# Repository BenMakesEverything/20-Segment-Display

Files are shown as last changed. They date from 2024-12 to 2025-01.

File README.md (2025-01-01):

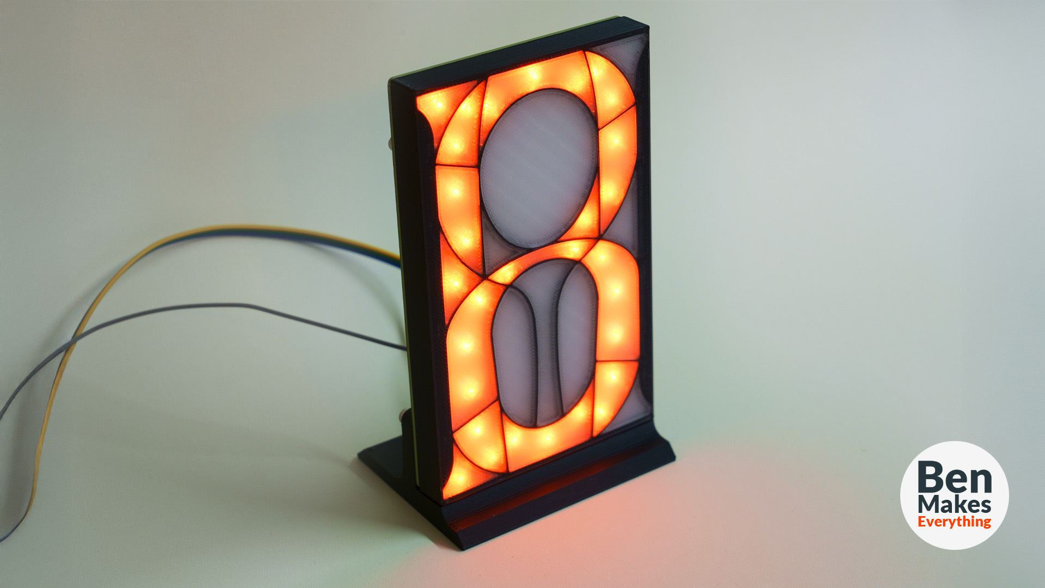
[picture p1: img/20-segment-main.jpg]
20 Segemnt 3D printed display


# 3D Printable 20 Segment Display
### This is a fully 3D printed segmented display designed for use with 5mm LEDs
You can use any type, but it was designed to be used in conjunction with the WS2812 through-hole type, soldered to a custom PCB.

# Parts list - for 1 display
* (38) WS2812 5mm LED: https://www.aliexpress.us/item/3256803179127817.html
* (1) 10uF capacitor
* (2) 1x3 male pin headers
* (1) PCB
* (4) M3 heat-set threaded inserts

All of the 3D files are available in .stl and .step format in the "Objects" folder.

The Arduino code for this version is available in the "Code" folder. It requires that you install the Adafruit neopixel libary within the Arduino IDE. There are now 2 versions: the standard one as seen in the video, and a scrolling version that lets you display longer messages.

In the "PCBs" folder you will find 2 zip files. 20-Segment-THT-KiCad.zip is a zipped folder of everything you need to open this in KiCad version 8+. 20-Segment-THT.kicad_pcb.zip contains gerber/drill files. Please note, the BOM file was auto generated, but I did not use it in getting these manufactured and can't confirm that the info is correct. I manually soldered the parts myself so if you want to get these manufactured in complete form, you'll likely need to specify the part numbers yourself.

The KiCad symbols and footprints for the WS2812 were based on these, created by bitluni: (https://github.com/bitluni/magnetMatrix6x6).

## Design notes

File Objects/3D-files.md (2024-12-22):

20-segment-body: the main display panel, for use with 5mm LEDs. Print with black and clear PETG.
20-segment-stand-left-end: use this for the left-most panel's stand
20-segment-stand-middle: use this for the middle panels' stands
20-segment-stand-right-end: use this for the right-most panel's stand

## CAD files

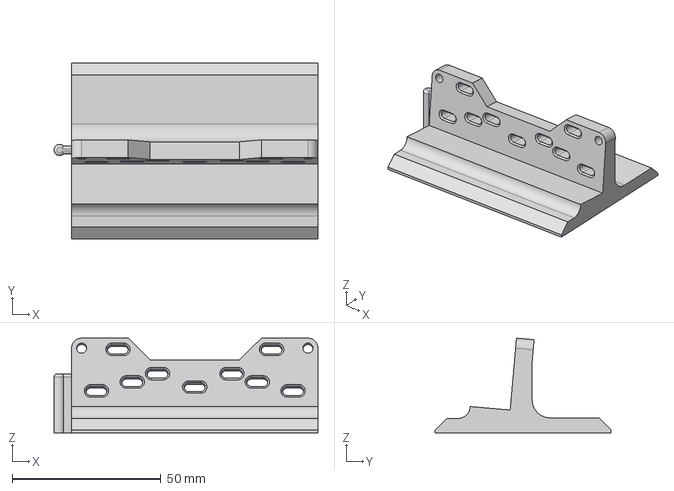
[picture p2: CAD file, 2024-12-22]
Objects/20-segment-stand-right-end.step
88.7 x 58.9 x 31.8 mm

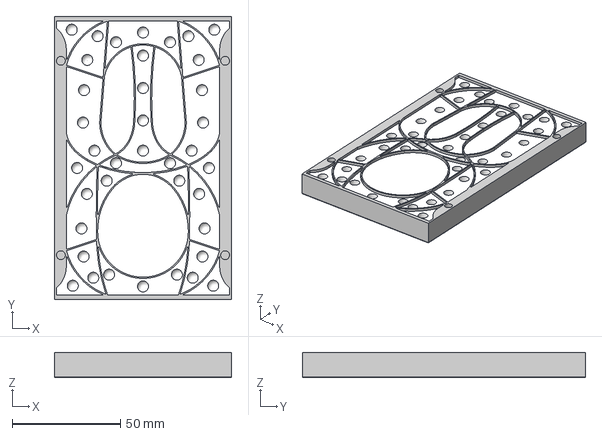
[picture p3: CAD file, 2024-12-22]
Objects/20-segment-body.step
82.0 x 131.0 x 11.6 mm

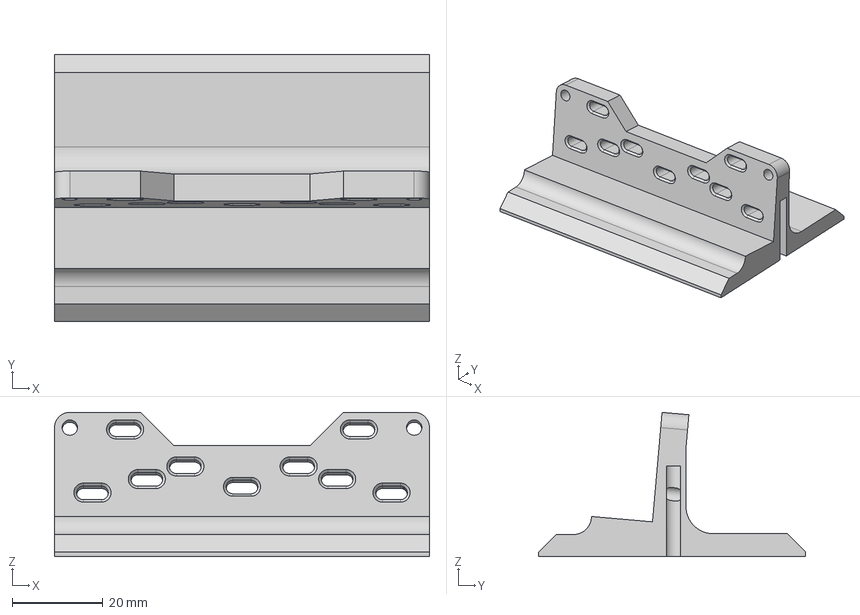
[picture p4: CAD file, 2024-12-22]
Objects/20-segment-stand-left-end.step
82.7 x 58.9 x 31.8 mm

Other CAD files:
Objects/20-segment-stand-middle.step
Objects/20-segment-body.stl
Objects/20-segment-stand-left-end.stl
Objects/20-segment-stand-middle.stl
Objects/20-segment-stand-right-end.stl

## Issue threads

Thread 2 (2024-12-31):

I think that a middle I and T actually look pretty OK

traverseda, 2024-12-31:
Can't include image links in youtube, so I'll post it here.

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

BenMakesEverything, 2025-01-02:
Those are certainly an option - I mainly didn't like the center bar sticking out like that. For now, I've just changed the t to a lower case version, at the suggestion of a couple people in the comments.
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

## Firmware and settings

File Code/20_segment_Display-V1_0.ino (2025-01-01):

/*Created by: Ben Makes Everything - youtube.com/@benmakeseverything*/
#include <Adafruit_NeoPixel.h>

#define dataPin 3      //Neopixel control dataPin
#define NUM_PANELS 10  //Number of display panels chained together

int numPixels = NUM_PANELS * 38;  // Total number of NeoPixels - 38 per display

Adafruit_NeoPixel pixels = Adafruit_NeoPixel(numPixels, dataPin, NEO_RGB + NEO_KHZ800);

const byte numChars = 11;  //MAX ammount of chars that can be input = #displays + 1
char myData[numChars];     // an array to store the received data
boolean newData = false;   // for checking serial

int digit = 0;

//Byte data array for all characters, follows pixel order from PCB
const uint8_t digitSegments[][5] = {
  { 0b00000000, 0b00000000, 0b00000000, 0b00000000, 0b00000000 }, /*SPACE*/
  { 0b00000011, 0b11101111, 0b10111101, 0b11101111, 0b10111000 }, /*0*/
  { 0b00000011, 0b11110000, 0b00000000, 0b00000001, 0b11111000 }, /*1*/
  { 0b00001100, 0b01111111, 0b10111000, 0b01101111, 0b10110100 }, /*2*/
  { 0b00001111, 0b11101111, 0b10000000, 0b01101111, 0b10110100 }, /*3*/
  { 0b00001111, 0b11110000, 0b00000011, 0b11110001, 0b11111000 }, /*4*/
  { 0b00001111, 0b11101111, 0b10000011, 0b11111111, 0b11000000 }, /*5*/
  { 0b00001111, 0b11101111, 0b10111101, 0b11101111, 0b10000000 }, /*6*/
  { 0b00001100, 0b00000001, 0b11111000, 0b01111111, 0b11110100 }, /*7*/
  { 0b00001111, 0b11101111, 0b10111011, 0b11101111, 0b10110100 }, /*8*/
  { 0b00001111, 0b11101111, 0b10000011, 0b11101111, 0b10111100 }, /*9*/
  { 0b00001111, 0b11110001, 0b11111101, 0b11101111, 0b10111000 }, /*A*/
  { 0b00001111, 0b11101111, 0b11111101, 0b11111111, 0b10110100 }, /*B*/
  { 0b00000000, 0b01101111, 0b10111101, 0b11101111, 0b10000000 }, /*C*/
  { 0b00000011, 0b11101111, 0b11111101, 0b11111111, 0b10111000 }, /*D*/
  { 0b00001100, 0b01111111, 0b11111101, 0b11111111, 0b11000000 }, /*E*/
  { 0b00001100, 0b00000001, 0b11111101, 0b11111111, 0b11000000 }, /*F*/
  { 0b00000011, 0b11111111, 0b10111101, 0b11101111, 0b10000000 }, /*G*/
  { 0b00001111, 0b11110001, 0b11111101, 0b11110001, 0b11111000 }, /*H*/
  { 0b00000011, 0b11110000, 0b00000000, 0b00000001, 0b11111000 }, /*I*/
  { 0b00000011, 0b11101111, 0b10000000, 0b00000001, 0b11111000 }, /*J*/
  { 0b00001111, 0b11110001, 0b11111101, 0b11110000, 0b00110100 }, /*K*/
  { 0b00000000, 0b01111111, 0b11111101, 0b11110000, 0b00000000 }, /*L*/
  { 0b11111111, 0b11110001, 0b11111111, 0b11110001, 0b11111100 }, /*M*/
  { 0b00000011, 0b11110001, 0b11111101, 0b11111111, 0b10111000 }, /*N*/
  { 0b00000011, 0b11101111, 0b10111101, 0b11101111, 0b10111000 }, /*O*/
  { 0b00001100, 0b00000001, 0b11111101, 0b11111111, 0b10110100 }, /*P*/
  { 0b00000011, 0b11111111, 0b10111101, 0b11101111, 0b10111000 }, /*Q*/
  { 0b00001111, 0b11110001, 0b11111101, 0b11111111, 0b10110100 }, /*R*/
  { 0b00001111, 0b11101111, 0b10000011, 0b11101111, 0b10000000 }, /*S*/
  //{ 0b00000011, 0b11110000, 0b00000000, 0b01111111, 0b11111000 }, /*T (uppercase)*/
  { 0b00001100, 0b01101111, 0b10111101, 0b11110000, 0b00000000 }, /*t (lowercase)*/
  { 0b00000011, 0b11111111, 0b11111101, 0b11110001, 0b11111000 }, /*U*/
  { 0b00000011, 0b11101111, 0b10111101, 0b11110001, 0b11111000 }, /*V*/
  { 0b11110011, 0b11111111, 0b11111101, 0b11110001, 0b11111000 }, /*W*/
  { 0b00001111, 0b11110001, 0b11111011, 0b11110001, 0b11110100 }, /*X*/
  { 0b00001111, 0b11101111, 0b10000011, 0b11110001, 0b11111100 }, /*Y*/
  { 0b00001100, 0b01111111, 0b11111000, 0b01111111, 0b11110100 }, /*Z*/
  { 0b00000000, 0b00000000, 0b01000000, 0b00000000, 0b00000000 }, /*.*/
  { 0b00001100, 0b00000000, 0b01111000, 0b01101111, 0b10110100 }, /*?*/
  { 0b00000000, 0b00000000, 0b01111101, 0b11110000, 0b00000000 }, /*!*/
  { 0b00001100, 0b00000000, 0b00000000, 0b00000000, 0b00000000 }  /*-*/
};

//This determines the color to be used in each panel
//you can set the all to the same for mono-color text, or define individually
const uint32_t digitColors[10] = {
  pixels.Color(225, 30, 0), //Panel 1
  pixels.Color(225, 30, 0), //Panel 2
  pixels.Color(225, 30, 0), //Panel 3
  pixels.Color(225, 30, 0), //Panel 4
  pixels.Color(225, 30, 0), //Panel 5
  pixels.Color(225, 30, 0), //Panel 6
  pixels.Color(225, 30, 0), //Panel 7
  pixels.Color(225, 30, 0), //Panel 8
  pixels.Color(225, 30, 0), //Panel 9
  pixels.Color(225, 30, 0), //Panel 10
};

/*For quick reference - some colors/values:
//Reds
(255, 0, 0),      //Pure Red
(200, 0, 55),     //Hot Pink
(245, 0, 10),     //Salmon
(225, 30, 0),     //Orange
(155, 100, 0),    //bright yellow
(180, 75, 0),     //Gold
(0, 255, 0),      //Pure Green
(55, 200, 0),     //Lime
(0, 225, 30)      //Teal
(0, 180, 75),     //Cyan
(0, 180, 75),     //Sky Blue
(0, 0, 255),      //Pure Blue
(55,0,200),       //Purple
(85, 85, 85),     //white - brightness balanced w/ other colors
(255, 255, 255),  //white - Full brightness
*/

void setup() {
  pixels.begin();  // Initialize the NeoPixel library
  pixels.show();   // Initialize all pixels to 'off'
  Serial.begin(9600);
}

void loop() {
  receiveData();
  showNewData();
  determineDigit();
  pixels.show();  // Update the NeoPixels to show the new states
  delay(100);     // Delay before showing the next digit
}

//This figures out what pixels to turn on based on the input character
void determineDigit() {
  for (int panNum = 0; panNum < NUM_PANELS; panNum++) {
    if (strlen(myData) > 0) {
      switch (tolower(myData[panNum])) {  // Convert the character to lowercase before checking
        case '0':
          digit = 1;
          break;
        case '1':
          digit = 2;
          break;
        case '2':
          digit = 3;
          break;
        case '3':
          digit = 4;
          break;
        case '4':
          digit = 5;
          break;
        case '5':
          digit = 6;
          break;
        case '6':
          digit = 7;
          break;
        case '7':
          digit = 8;
          break;
        case '8':
          digit = 9;
          break;
        case '9':
          digit = 10;
          break;
        case 'a':
          digit = 11;
          break;
        case 'b':
          digit = 12;
          break;
        case 'c':
          digit = 13;
          break;
        case 'd':
          digit = 14;
          break;
        case 'e':
          digit = 15;
          break;
        case 'f':
          digit = 16;
          break;
        case 'g':
          digit = 17;
          break;
        case 'h':
          digit = 18;
          break;
        case 'i':
          digit = 19;
          break;
        case 'j':
          digit = 20;
          break;
        case 'k':
          digit = 21;
          break;
        case 'l':
          digit = 22;
          break;
        case 'm':
          digit = 23;
          break;
        case 'n':
          digit = 24;
          break;
        case 'o':
          digit = 25;
          break;
        case 'p':
          digit = 26;
          break;
        case 'q':
          digit = 27;
          break;
        case 'r':
          digit = 28;
          break;
        case 's':
          digit = 29;
          break;
        case 't':
          digit = 30;
          break;
        case 'u':
          digit = 31;
          break;
        case 'v':
          digit = 32;
          break;
        case 'w':
          digit = 33;
          break;
        case 'x':
          digit = 34;
          break;
        case 'y':
          digit = 35;
          break;
        case 'z':
          digit = 36;
          break;
        case '.':
          digit = 37;
          break;
        case '?':
          digit = 38;
          break;
        case '!':
          digit = 39;
          break;
        case '-':
          digit = 40;
          break;
        default:
          digit = 0;
          break;
      }
    } else {
      digit = 0;
    }

    // Loop through the 5 bytes of each character (digit or letter)
    for (int byteIndex = 0; byteIndex < 5; byteIndex++) {
      uint8_t byteValue = digitSegments[digit][byteIndex];

      // Loop through each bit of the byte (8 bits per byte)
      for (int bitIndex = 0; bitIndex < 8; bitIndex++) {
        int pixelIndex = byteIndex * 8 + bitIndex;  // Calculate pixel index from byte and bit

        pixelIndex = pixelIndex + (panNum * 38);

        bool bitValue = (byteValue >> (7 - bitIndex)) & 1;  // Extract the bit value (1 or 0)

        // If the bit is 1, turn the pixel on; if it's 0, turn it off
        if (bitValue) {
          pixels.setPixelColor(pixelIndex, digitColors[panNum]);  //Set the LED to the correct color
        } else {
          pixels.setPixelColor(pixelIndex, pixels.Color(0, 0, 0));  // Turn off the LED
        }
      }
    }
  }
}

void receiveData() {
  static byte ndx = 0;
  char endMarker = '\n';
  char rc;

  while (Serial.available() > 0 && newData == false) {
    rc = Serial.read();
    if (rc != endMarker) {
      myData[ndx] = rc;
      ndx++;
      if (ndx >= numChars) {
        ndx = numChars - 1;
      }
    } else {
      myData[ndx] = '\0';  // terminate the string
      ndx = 0;
      newData = true;
    }
  }
}

void showNewData() {
  if (newData == true) {
    newData = false;
  }
}
